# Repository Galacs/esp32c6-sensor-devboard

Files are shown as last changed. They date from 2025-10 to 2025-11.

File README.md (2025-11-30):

# ESP32-C6 Sensor-Devboard

ESP32-C6 sensor test board made to test step-down power supply design, wide input AC/DC level shifter, i2c temperature sensors, sdio sdcard and RF circuit (IEEE 802.15.4)

## IC List

- ESP32-C6 (Main MCU)
- W25Q128JVSIQ (16MB program storage spi flash)
- TCA9555 (I2C I/O expander)
- 2x TMP117 (I2C temperature sensor)
- BMP581 (I2C/SPI pressure sensor)
- 3x LM393 (comparator)
- 2x LMR36520 (wide Vin buck converter)
- LM317A (high Vin LDO)
- AP2112K (MCU LDO)
- 2x CJ431 (Voltage references)
- 2450AT18A100E (2.45GHz Ceramic chip antenna)

## Top preview



## Preview 3d render



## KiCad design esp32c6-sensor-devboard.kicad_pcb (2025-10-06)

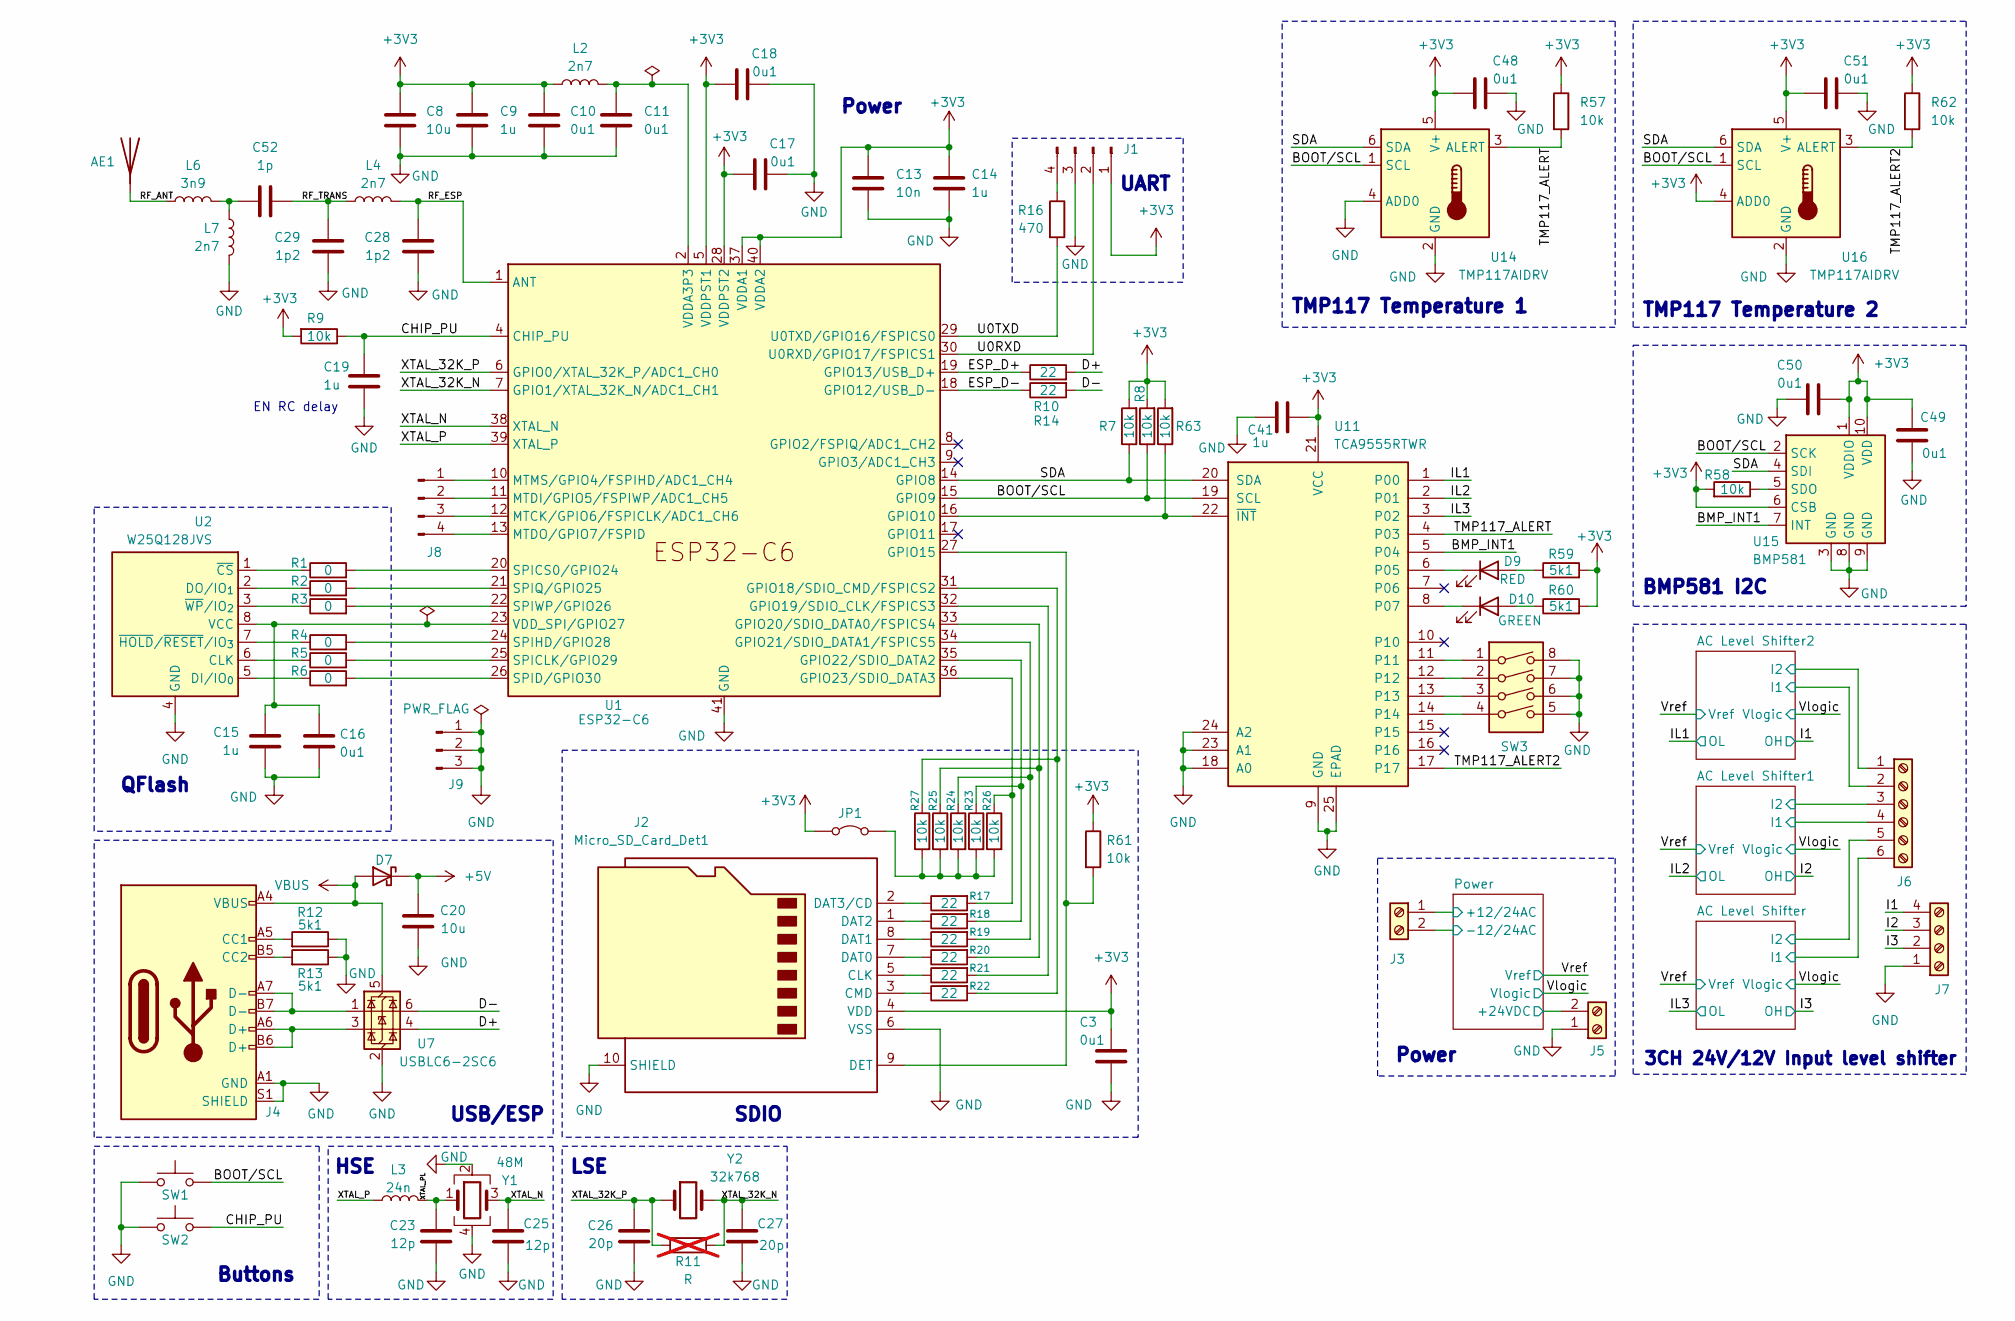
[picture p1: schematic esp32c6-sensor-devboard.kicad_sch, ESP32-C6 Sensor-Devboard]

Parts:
AE1: Antenna; Johanson_2450AT18x100; Manufacturer Part Number 2450AT18A100E; JLCPCB Part # C89334
C3: 0u1; C_0603_1608Metric; Manufacturer Part Number CC0603KRX7R9BB104; JLCPCB Part # C14663
C8, C20: 10u; C_0402_1005Metric; Manufacturer Part Number CL05A106MQ5NUNC; JLCPCB Part # C15525
C9, C14, C15, C19, C41: 1u; C_0402_1005Metric; Manufacturer Part Number CL05A105KA5NQNC; JLCPCB Part # C52923
C10, C11, C16, C17, C18, C48, C49, C50, C51: 0u1; C_0402_1005Metric; Manufacturer Part Number CL05B104KB54PNC; JLCPCB Part # C307331
C13: 10n; C_0402_1005Metric; Manufacturer Part Number CL05B103KB5NNNC; JLCPCB Part # C15195
C23, C25: 12p; C_0402_1005Metric; Manufacturer Part Number 0402CG120J500NT; JLCPCB Part # C1547
C26, C27: 20p; C_0402_1005Metric; Manufacturer Part Number 0402CG200J500NT; JLCPCB Part # C1554
C28, C29: 1p2; C_0402_1005Metric; Manufacturer Part Number GJM1555C1H1R2WB01D; JLCPCB Part # C76899
C52: 1p; C_0402_1005Metric; Manufacturer Part Number 0402CG1R0C500NT; JLCPCB Part # C1550
D7: D_Schottky; D_SMA; Manufacturer Part Number SS54; JLCPCB Part # C22452
D9: RED; LED_0603_1608Metric; Manufacturer Part Number KT-0603R; JLCPCB Part # C2286
D10: GREEN; LED_0805_2012Metric; Manufacturer Part Number KT-0805G; JLCPCB Part # C2297
J1, J8: Conn_01x04_Pin; PinHeader_1x04_P2.54mm_Vertical
J2: Micro_SD_Card_Det1; microSD_Hanbo_TF012; Manufacturer Part Number TF-012; JLCPCB Part # C410350
J3, J5: Screw_Terminal_01x02; TerminalBlock_Altech_AK300-2_P5.00mm
J4: USB_C_Receptacle_USB2.0_14P; USB_C_Receptacle_HRO_TYPE-C-31-M-12; Manufacturer Part Number TYPE-C16PIN; JLCPCB Part # C393939
J6: Screw_Terminal_01x06; TerminalBlock_Phoenix_MKDS-1,5-6_1x06_P5.00mm_Horizontal
J7: Screw_Terminal_01x04; TerminalBlock_Altech_AK300-4_P5.00mm
J9: Conn_01x03_Pin; PinHeader_1x03_P2.54mm_Vertical
JP1: Jumper_2_Bridged; PinHeader_1x02_P2.54mm_Vertical
L2, L4: 2n7; L_0402_1005Metric; Manufacturer Part Number LQW15AN2N7G80D; JLCPCB Part # C412269
L3: 24n; L_0402_1005Metric; Manufacturer Part Number LQW15AN24NG00D; JLCPCB Part # C167472
L6: 3n9; L_0402_1005Metric; Manufacturer Part Number LQG15HS3N9S02D; JLCPCB Part # C77109
L7: 2n7; L_0402_1005Metric; Manufacturer Part Number LQG15HS2N7S02D; JLCPCB Part # C77108
R1, R2, R3, R4, R5, R6: 0; R_0402_1005Metric; Manufacturer Part Number 0402WGF0000TCE; JLCPCB Part # C17168
R7, R8, R9, R57, R58, R61, R62, R63: 10k; R_0603_1608Metric; Manufacturer Part Number 0603WAF1002T5E; JLCPCB Part # C25804
R10, R14, R17, R18, R19, R20, R21, R22: 22; R_0402_1005Metric; Manufacturer Part Number 0402WGF220JTCE; JLCPCB Part # C25092
R11: R; R_0603_1608Metric; not fitted
R12, R13, R59, R60: 5k1; R_0603_1608Metric; Manufacturer Part Number 0603WAF5101T5E; JLCPCB Part # C23186
R16: 470; R_0402_1005Metric; Manufacturer Part Number 0402WGF4700TCE; JLCPCB Part # C25117
R23, R24, R25, R26, R27: 10k; R_0402_1005Metric; Manufacturer Part Number 0402WGF1002TCE; JLCPCB Part # C25744
SW1, SW2: SW_Push; SW_SPST_TS-1088-xR020; Manufacturer Part Number TS-1088-AR02016; JLCPCB Part # C720477
SW3: SW_DIP_x04; SW_DIP_SPSTx04_Slide_9.78x12.34mm_W7.62mm_P2.54mm
U1: ESP32-C6; QFN-40-1EP_5x5mm_P0.4mm_EP3.6x3.6mm_ThermalVias; Manufacturer Part Number ESP32-C6; JLCPCB Part # C5364646
U2: W25Q128JVS; SOIC-8_5.3x5.3mm_P1.27mm; Manufacturer Part Number W25Q128JVSIQ; JLCPCB Part # C97521
U7: USBLC6-2SC6; SOT-23-6; Manufacturer Part Number USBLC6-2SC6; JLCPCB Part # C7519
U11: TCA9555RTWR; Texas_RTW_WQFN-24-1EP_4x4mm_P0.5mm_EP2.7x2.7mm_ThermalVias; Manufacturer Part Number TCA9555RTWR; JLCPCB Part # C140277
U14, U16: TMP117AIDRV; WSON-6-1EP_2x2mm_P0.65mm_EP1x1.6mm; Manufacturer Part Number TMP117AIDRVR; JLCPCB Part # C699536
U15: BMP581; Bosch_LGA-10_2x2mm_P0.8mm_AntiClockwisePinNumbering; Manufacturer Part Number BMP581; JLCPCB Part # C5362283
Y1: 48M; Crystal_SMD_2016-4Pin_2.0x1.6mm; Manufacturer Part Number R940000096; JLCPCB Part # C7206306
Y2: 32k768; Crystal_SMD_3215-2Pin_3.2x1.5mm; Manufacturer Part Number Q13FC13500004; JLCPCB Part # C32346

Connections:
+3V3: C3.1, C8.1, C9.1, C10.1, C13.1, C14.1, C17.1, C18.1, C41.2, C48.1, C49.2, C50.1, C51.1, J1.1, J2.4 (VDD), JP1.1 (A), L2.1, R7.2, R8.2, R9.2, R57.1, R58.2, R59.2, R60.2, R61.1, R62.1, R63.2, U1.5 (VDDPST1), U1.28 (VDDPST2), U1.37 (VDDA1), U1.40 (VDDA2), U11.21 (VCC), U14.5 (V+), U15.1 (VDDIO), U15.6 (CSB), U15.10 (VDD), U16.4 (ADD0), U16.5 (V+); also elsewhere on the board
+5V: C20.1, D7.1 (K); also elsewhere on the board
/AC Level Shifter1/I1: J6.4; also elsewhere on the board
/AC Level Shifter1/I2: J6.3; also elsewhere on the board
/AC Level Shifter2/I1: J6.2; also elsewhere on the board
/AC Level Shifter2/I2: J6.1; also elsewhere on the board
/AC Level Shifter/I1: J6.6; also elsewhere on the board
/AC Level Shifter/I2: J6.5; also elsewhere on the board
/BMP_INT1: U11.5 (P04), U15.7 (INT)
/BOOT/SCL: R8.1, SW1.2, U1.15 (GPIO9), U11.19 (SCL), U14.1 (SCL), U15.2 (SCK), U16.1 (SCL)
/CHIP_PU: C19.1, R9.1, SW2.2, U1.4 (CHIP_PU)
/D+: R10.2, U7.4 (I/O2)
/D-: R14.2, U7.6 (I/O1)
/ESP_D+: R10.1, U1.19 (GPIO13/USB_D+)
/ESP_D-: R14.1, U1.18 (GPIO12/USB_D-)
/I1: J7.4; also elsewhere on the board
/I2: J7.3; also elsewhere on the board
/I3: J7.2; also elsewhere on the board
/IL1: U11.1 (P00); also elsewhere on the board
/IL2: U11.2 (P01); also elsewhere on the board
/IL3: U11.3 (P02); also elsewhere on the board
/Power/+12/24AC: J3.1; also elsewhere on the board
/Power/+24VDC: J5.2; also elsewhere on the board
/Power/-12/24AC: J3.2; also elsewhere on the board
/RF_ANT: AE1.1 (A), L6.1
/RF_ESP: C28.1, L4.2, U1.1 (ANT)
/RF_TRANS: C29.1, C52.1, L4.1
/SDA: R7.1, U1.14 (GPIO8), U11.20 (SDA), U14.6 (SDA), U15.4 (SDI), U16.6 (SDA)
/TMP117_ALERT: R57.2, U11.4 (P03), U14.3 (ALERT)
/TMP117_ALERT2: R62.2, U11.17, U16.3 (ALERT)
/U0RXD: J1.2, U1.30 (U0RXD/GPIO17/FSPICS1)
/U0TXD: R16.2, U1.29 (U0TXD/GPIO16/FSPICS0)
/XTAL_32K_N: C27.1, R11.2, U1.7 (GPIO1/XTAL_32K_N/ADC1_CH1), Y2.2
/XTAL_32K_P: C26.2, R11.1, U1.6 (GPIO0/XTAL_32K_P/ADC1_CH0), Y2.1
/XTAL_N: C25.1, U1.38 (XTAL_N), Y1.3
/XTAL_P: L3.1, U1.39 (XTAL_P)
/XTAL_PL: C23.2, L3.2, Y1.1
GND: C3.2, C8.2, C9.2, C10.2, C11.2, C13.2, C14.2, C15.2, C16.2, C17.2, C18.2, C19.2, C20.2, C23.1, C25.2, C26.1, C27.2, C28.2, C29.2, C41.1, C48.2, C49.1, C50.2, C51.2, J1.3, J2.6 (VSS), J2.10 (SHIELD), J4.A1 (GND), J4.A12 (GND), J4.B1 (GND), J4.B12 (GND), J4.S1 (SHIELD), J5.1, J7.1, J9.1, J9.2, J9.3, L7.1, R12.1, R13.1, SW1.1, SW2.1, SW3.5, SW3.6, SW3.7, SW3.8, U1.41 (GND), U2.4 (GND), U7.2 (GND), U11.9 (GND), U11.18 (A0), U11.23 (A1), U11.24 (A2), U11.25 (EPAD), U14.2 (GND), U14.4 (ADD0), U15.3 (GND), U15.8 (GND), U15.9 (GND), U16.2 (GND), U16.7, Y1.2, Y1.4; also elsewhere on the board
unnamed: C11.1, L2.2, U1.2 (VDDA3P3), U1.3 (VDDA3P3)
unnamed: C52.2, L6.2, L7.2
unnamed: D9.2 (A), R59.1
unnamed: D9.1 (K), U11.6 (P05)
unnamed: D10.2 (A), R60.1
unnamed: D10.1 (K), U11.8 (P07)
unnamed: J1.4, R16.1
unnamed: J2.5 (CLK), R21.1
unnamed: J2.3 (CMD), R22.1
unnamed: J2.7 (DAT0), R20.1
unnamed: J2.8 (DAT1), R19.1
unnamed: J2.1 (DAT2), R18.1
unnamed: J2.2 (DAT3/CD), R17.1
unnamed: J2.9 (DET), R61.2, U1.27 (GPIO15)
unnamed: J4.A5 (CC1), R12.2
unnamed: J4.B5 (CC2), R13.2
unnamed: J4.A6 (D+), J4.B6 (D+), U7.3 (I/O2)
unnamed: J4.A7 (D-), J4.B7 (D-), U7.1 (I/O1)
unnamed: J8.1, U1.10 (MTMS/GPIO4/FSPIHD/ADC1_CH4)
unnamed: J8.2, U1.11 (MTDI/GPIO5/FSPIWP/ADC1_CH5)
unnamed: J8.3, U1.12 (MTCK/GPIO6/FSPICLK/ADC1_CH6)
unnamed: J8.4, U1.13 (MTDO/GPIO7/FSPID)
unnamed: JP1.2 (B), R23.2, R24.2, R25.2, R26.2, R27.2
unnamed: R63.1, U1.16 (GPIO10), U11.22 (~INT)
unnamed: R22.2, R27.1, U1.31 (GPIO18/SDIO_CMD/FSPICS2)
unnamed: R21.2, U1.32 (GPIO19/SDIO_CLK/FSPICS3)
unnamed: R20.2, R25.1, U1.33 (GPIO20/SDIO_DATA0/FSPICS4)
unnamed: R19.2, R24.1, U1.34 (GPIO21/SDIO_DATA1/FSPICS5)
unnamed: R18.2, R23.1, U1.35 (GPIO22/SDIO_DATA2)
unnamed: R17.2, R26.1, U1.36 (GPIO23/SDIO_DATA3)
unnamed: R5.2, U1.25 (SPICLK/GPIO29)
unnamed: R1.2, U1.20 (SPICS0/GPIO24)
unnamed: R6.2, U1.26 (SPID/GPIO30)
unnamed: R4.2, U1.24 (SPIHD/GPIO28)
unnamed: R2.2, U1.21 (SPIQ/GPIO25)
unnamed: R3.2, U1.22 (SPIWP/GPIO26)
unnamed: C15.1, C16.1, U1.23 (VDD_SPI/GPIO27), U2.8 (VCC)
unnamed: R5.1, U2.6 (CLK)
unnamed: R6.1, U2.5 (DI/IO_{0})
unnamed: R2.1, U2.2 (DO/IO_{1})
unnamed: R1.1, U2.1 (~CS)
unnamed: R4.1, U2.7 (~HOLD/~RESET/IO_{3})
unnamed: R3.1, U2.3 (~WP/IO_{2})
unnamed: SW3.1, U11.11
unnamed: SW3.2, U11.12
unnamed: SW3.3, U11.13
unnamed: SW3.4, U11.14
unnamed: R58.1, U15.5 (SDO)
TMP117_1_PAD: U14.7
VBUS: D7.2 (A), J4.A4 (VBUS), J4.A9 (VBUS), J4.B4 (VBUS), J4.B9 (VBUS), U7.5 (VBUS)

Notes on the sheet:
BMP581 I2C
TMP117 Temperature 2
EN RC delay
HSE
3CH 24V/12V Input level shifter
SDIO
LSE
TMP117 Temperature 1
QFlash
Power
USB/ESP
Buttons
UART

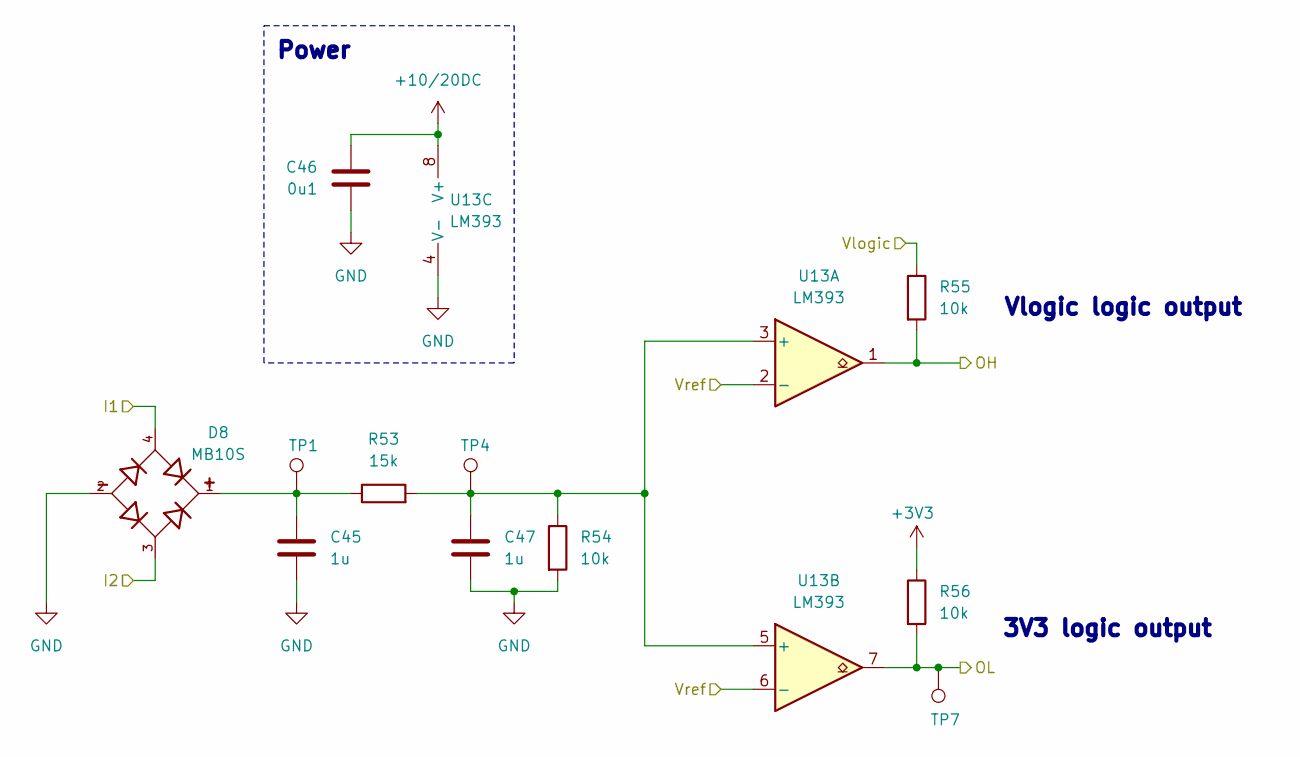
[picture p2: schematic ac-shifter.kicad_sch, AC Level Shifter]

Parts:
C45: 1u; C_0603_1608Metric; Manufacturer Part Number CL10A105KB8NNNC; JLCPCB Part # C15849
C46: 0u1; C_0402_1005Metric; Manufacturer Part Number CL05B104KB54PNC; JLCPCB Part # C307331
C47: 1u; C_0402_1005Metric; Manufacturer Part Number CL05A105KA5NQNC; JLCPCB Part # C52923
D8: MB10S; OnSemi_751EP_SOIC-4_3.9x4.725mm_P2.54mm; Manufacturer Part Number C2488; JLCPCB Part # C2488
R53: 15k; R_0603_1608Metric; Manufacturer Part Number 0603WAF1502T5E; JLCPCB Part # C22809
R54, R55, R56: 10k; R_0603_1608Metric; Manufacturer Part Number 0603WAF1002T5E; JLCPCB Part # C25804
TP1, TP4, TP7: TestPoint; TestPoint_Pad_D2.0mm
U13: LM393; SOIC-8_3.9x4.9mm_P1.27mm; Manufacturer Part Number LM393DR2G; JLCPCB Part # C7955

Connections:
+3V3: R56.1; also elsewhere on the board
+10/20DC: C46.1, U13.8 (V+); also elsewhere on the board
/AC Level Shifter/I1: D8.4; also elsewhere on the board
/AC Level Shifter/I2: D8.3; also elsewhere on the board
/I3: R55.2, U13.1; also elsewhere on the board
/IL3: R56.2, TP7.1, U13.7; also elsewhere on the board
/Vlogic: R55.1; also elsewhere on the board
/Vref: U13.2 (-), U13.6 (-); also elsewhere on the board
GND: C45.2, C46.2, C47.2, D8.2, R54.2, U13.4 (V-); also elsewhere on the board
unnamed: C45.1, D8.1, R53.1, TP1.1
unnamed: C47.1, R53.2, R54.1, TP4.1, U13.3 (+), U13.5 (+)

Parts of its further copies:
C32, C42: 1u; C_0603_1608Metric; Manufacturer Part Number CL10A105KB8NNNC; JLCPCB Part # C15849
C39, C43: 0u1; C_0402_1005Metric; Manufacturer Part Number CL05B104KB54PNC; JLCPCB Part # C307331
C40, C44: 1u; C_0402_1005Metric; Manufacturer Part Number CL05A105KA5NQNC; JLCPCB Part # C52923
D5, D6: MB10S; OnSemi_751EP_SOIC-4_3.9x4.725mm_P2.54mm; Manufacturer Part Number C2488; JLCPCB Part # C2488
R37, R49: 15k; R_0603_1608Metric; Manufacturer Part Number 0603WAF1502T5E; JLCPCB Part # C22809
R39, R47, R48, R50, R51, R52: 10k; R_0603_1608Metric; Manufacturer Part Number 0603WAF1002T5E; JLCPCB Part # C25804
TP2, TP3, TP5, TP6, TP8, TP9: TestPoint; TestPoint_Pad_D2.0mm
U10, U12: LM393; SOIC-8_3.9x4.9mm_P1.27mm; Manufacturer Part Number LM393DR2G; JLCPCB Part # C7955

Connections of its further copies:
+3V3: R48.1, R52.1; also elsewhere on the board
+10/20DC: C39.1, C43.1, U10.8 (V+), U12.8 (V+); also elsewhere on the board
/AC Level Shifter1/I1: D6.4; also elsewhere on the board
/AC Level Shifter1/I2: D6.3; also elsewhere on the board
/AC Level Shifter2/I1: D5.4; also elsewhere on the board
/AC Level Shifter2/I2: D5.3; also elsewhere on the board
/I1: R47.2, U10.1; also elsewhere on the board
/I2: R51.2, U12.1; also elsewhere on the board
/IL1: R48.2, TP9.1, U10.7; also elsewhere on the board
/IL2: R52.2, TP8.1, U12.7; also elsewhere on the board
/Vlogic: R47.1, R51.1; also elsewhere on the board
/Vref: U10.2 (-), U10.6 (-), U12.2 (-), U12.6 (-); also elsewhere on the board
GND: C32.2, C39.2, C40.2, C42.2, C43.2, C44.2, D5.2, D6.2, R39.2, R50.2, U10.4 (V-), U12.4 (V-); also elsewhere on the board
unnamed: C32.1, D5.1, R37.1, TP3.1
unnamed: C42.1, D6.1, R49.1, TP2.1
unnamed: C40.1, R37.2, R39.1, TP6.1, U10.3 (+), U10.5 (+)
unnamed: C44.1, R49.2, R50.1, TP5.1, U12.3 (+), U12.5 (+)

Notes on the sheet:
Power
3V3 logic output
Vlogic logic output

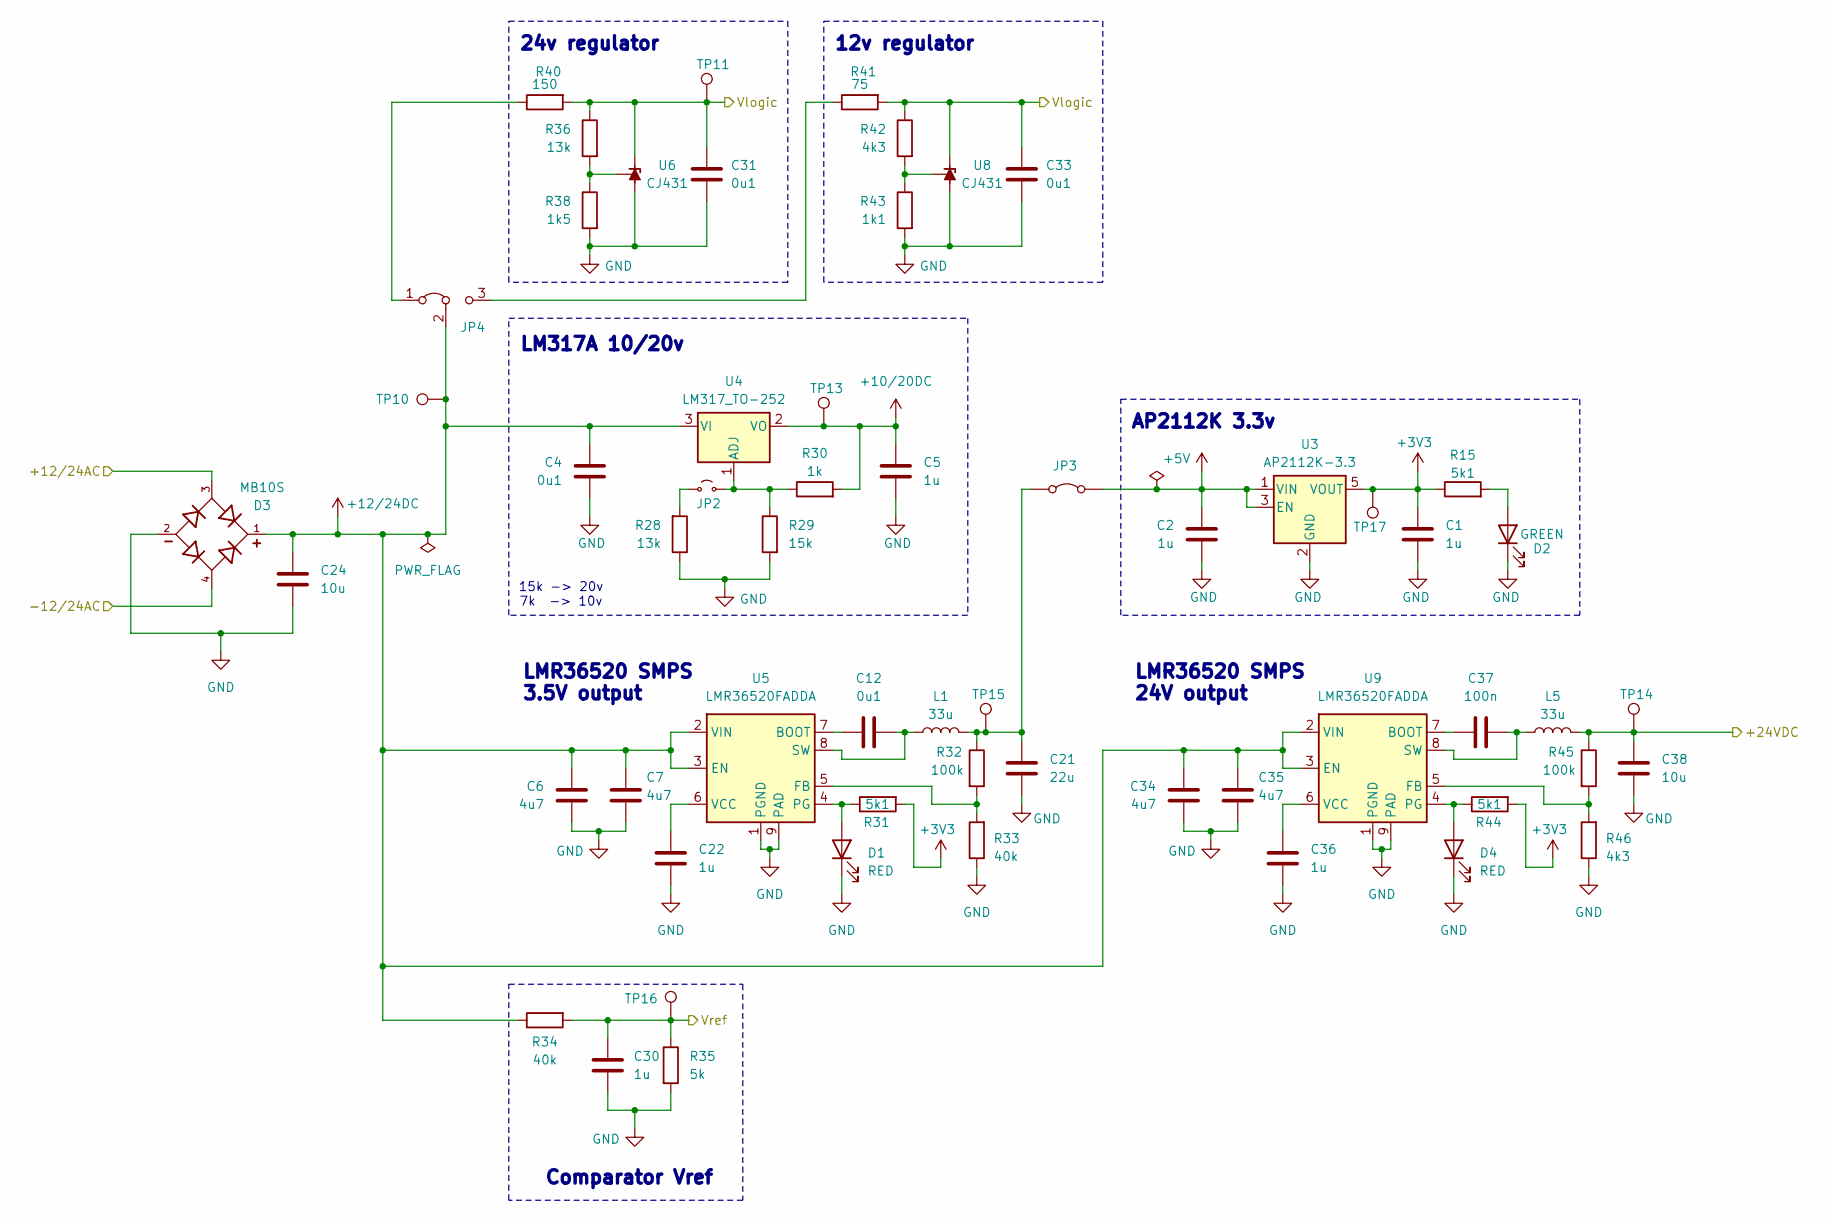
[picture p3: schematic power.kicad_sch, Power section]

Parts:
C1, C2, C5: 1u; C_0603_1608Metric; Manufacturer Part Number CL10A105KB8NNNC; JLCPCB Part # C15849
C4: 0u1; C_0603_1608Metric; Manufacturer Part Number CC0603KRX7R9BB104; JLCPCB Part # C14663
C6, C7, C34, C35: 4u7; C_1206_3216Metric; Manufacturer Part Number 1206B475K500NT; JLCPCB Part # C29823
C12, C31, C33: 0u1; C_0402_1005Metric; Manufacturer Part Number CL05B104KB54PNC; JLCPCB Part # C307331
C21: 22u; C_0603_1608Metric; Manufacturer Part Number CL10A226MQ8NRNC; JLCPCB Part # C59461
C22, C30, C36: 1u; C_0402_1005Metric; Manufacturer Part Number CL05A105KA5NQNC; JLCPCB Part # C52923
C24: 10u; C_0805_2012Metric; Manufacturer Part Number GRM21BR61H106KE43L; JLCPCB Part # C440198
C37: 100n; C_0402_1005Metric; Manufacturer Part Number CL05B104KB54PNC; JLCPCB Part # C307331
C38: 10u; C_0603_1608Metric; Manufacturer Part Number CL10A106MA8NRNC; JLCPCB Part # C96446
D1, D4: RED; LED_0603_1608Metric; Manufacturer Part Number KT-0603R; JLCPCB Part # C2286
D2: GREEN; LED_0805_2012Metric; Manufacturer Part Number KT-0805G; JLCPCB Part # C2297
D3: MB10S; OnSemi_751EP_SOIC-4_3.9x4.725mm_P2.54mm; Manufacturer Part Number C2488; JLCPCB Part # C2488
JP2: Jumper_2_Small_Open; PinHeader_1x02_P2.54mm_Vertical
JP3: Jumper_2_Bridged; PinHeader_1x02_P2.54mm_Vertical
JP4: Jumper_3_Bridged12; PinHeader_1x03_P2.54mm_Vertical
L1, L5: 33u; L_Chilisin_BMRx00060630; Manufacturer Part Number FXL0630-330-M; JLCPCB Part # C177245
R15, R31, R44: 5k1; R_0603_1608Metric; Manufacturer Part Number 0603WAF5101T5E; JLCPCB Part # C23186
R28, R36: 13k; R_0603_1608Metric; Manufacturer Part Number 0603WAF1302T5E; JLCPCB Part # C22797
R29: 15k; R_0603_1608Metric; Manufacturer Part Number 0603WAF1502T5E; JLCPCB Part # C22809
R30: 1k; R_0603_1608Metric; Manufacturer Part Number 0603WAF1001T5E; JLCPCB Part # C21190
R32, R45: 100k; R_0603_1608Metric; Manufacturer Part Number 0603WAF1003T5E; JLCPCB Part # C25803
R33, R34: 40k; R_0603_1608Metric; Manufacturer Part Number 0603WAF4022T5E; JLCPCB Part # C12447
R35: 5k; R_0603_1608Metric; Manufacturer Part Number 0603WAF4991T5E; JLCPCB Part # C23046
R38: 1k5; R_0603_1608Metric; Manufacturer Part Number 0603WAF1501T5E; JLCPCB Part # C22843
R40: 150; R_0805_2012Metric; Manufacturer Part Number 0805W8F1500T5E; JLCPCB Part # C17471
R41: 75; R_0805_2012Metric; Manufacturer Part Number 0805W8F750JT5E; JLCPCB Part # C20638
R42, R46: 4k3; R_0603_1608Metric; Manufacturer Part Number 0603WAF4301T5E; JLCPCB Part # C23159
R43: 1k1; R_0603_1608Metric; Manufacturer Part Number 0603WAF1101T5E; JLCPCB Part # C22764
TP10, TP11, TP13, TP14, TP15, TP16, TP17: TestPoint; TestPoint_Pad_D2.0mm
U3: AP2112K-3.3; SOT-23-5; Manufacturer Part Number AP2112K-3.3TRG1; JLCPCB Part # C51118
U4: LM317_TO-252; TO-252-2; Manufacturer Part Number LM317AG-TN3-R; JLCPCB Part # C75510
U5, U9: LMR36520FADDA; Texas_HTSOP-8-1EP_3.9x4.9mm_P1.27mm_EP2.95x4.9mm_Mask2.4x3.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; Manufacturer Part Number LMR36520FADDAR; JLCPCB Part # C1858395
U6, U8: CJ431; SOT-23; Manufacturer Part Number CJ431; JLCPCB Part # C3113

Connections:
+3V3: C1.1, R15.1, R31.2, R44.2, TP17.1, U3.5 (VOUT); also elsewhere on the board
+5V: C2.1, JP3.2 (B), U3.1 (VIN), U3.3 (EN); also elsewhere on the board
+10/20DC: C5.1, R30.2, TP13.1, U4.2 (VO); also elsewhere on the board
+12/24DC: C4.1, C6.1, C7.1, C24.1, C34.1, C35.1, D3.1, JP4.2 (C), R34.1, TP10.1, U4.3 (VI), U5.2 (VIN), U5.3 (EN), U9.2 (VIN), U9.3 (EN)
/Power/+12/24AC: D3.3; also elsewhere on the board
/Power/+24VDC: C38.2, L5.2, R45.1, TP14.1; also elsewhere on the board
/Power/-12/24AC: D3.4; also elsewhere on the board
/Vlogic: C31.1, C33.1, R36.1, R40.2, R41.2, R42.1, TP11.1, U6.2 (K), U8.2 (K); also elsewhere on the board
/Vref: C30.1, R34.2, R35.1, TP16.1; also elsewhere on the board
GND: C1.2, C2.2, C4.2, C5.2, C6.2, C7.2, C21.1, C22.2, C24.2, C30.2, C31.2, C33.2, C34.2, C35.2, C36.2, C38.1, D1.1 (K), D2.1 (K), D3.2, D4.1 (K), R28.1, R29.2, R33.1, R35.2, R38.2, R43.2, R46.1, U3.2 (GND), U5.1 (PGND), U5.9 (PAD), U6.3 (A), U8.3 (A), U9.1 (PGND), U9.9 (PAD); also elsewhere on the board
unnamed: D1.2 (A), R31.1, U5.4 (PG)
unnamed: D2.2 (A), R15.2
unnamed: D4.2 (A), R44.1, U9.4 (PG)
unnamed: JP2.1 (A), R28.2
unnamed: JP2.2 (B), R29.1, R30.1, U4.1 (ADJ)
unnamed: C21.2, JP3.1 (A), L1.2, R32.1, TP15.1
unnamed: JP4.1 (A), R40.1
unnamed: JP4.3 (B), R41.1
unnamed: C12.2, U5.7 (BOOT)
unnamed: R32.2, R33.2, U5.5 (FB)
unnamed: C12.1, L1.1, U5.8 (SW)
unnamed: C22.1, U5.6 (VCC)
unnamed: R36.2, R38.1, U6.1 (REF)
unnamed: R42.2, R43.1, U8.1 (REF)
unnamed: C37.2, U9.7 (BOOT)
unnamed: R45.2, R46.2, U9.5 (FB)
unnamed: C37.1, L5.1, U9.8 (SW)
unnamed: C36.1, U9.6 (VCC)

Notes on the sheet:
Comparator Vref
LMR36520 SMPS 3.5V output
AP2112K 3.3v
12v regulator
15k -> 20v 7k -> 10v
24v regulator
LMR36520 SMPS 24V output
LM317A 10/20v

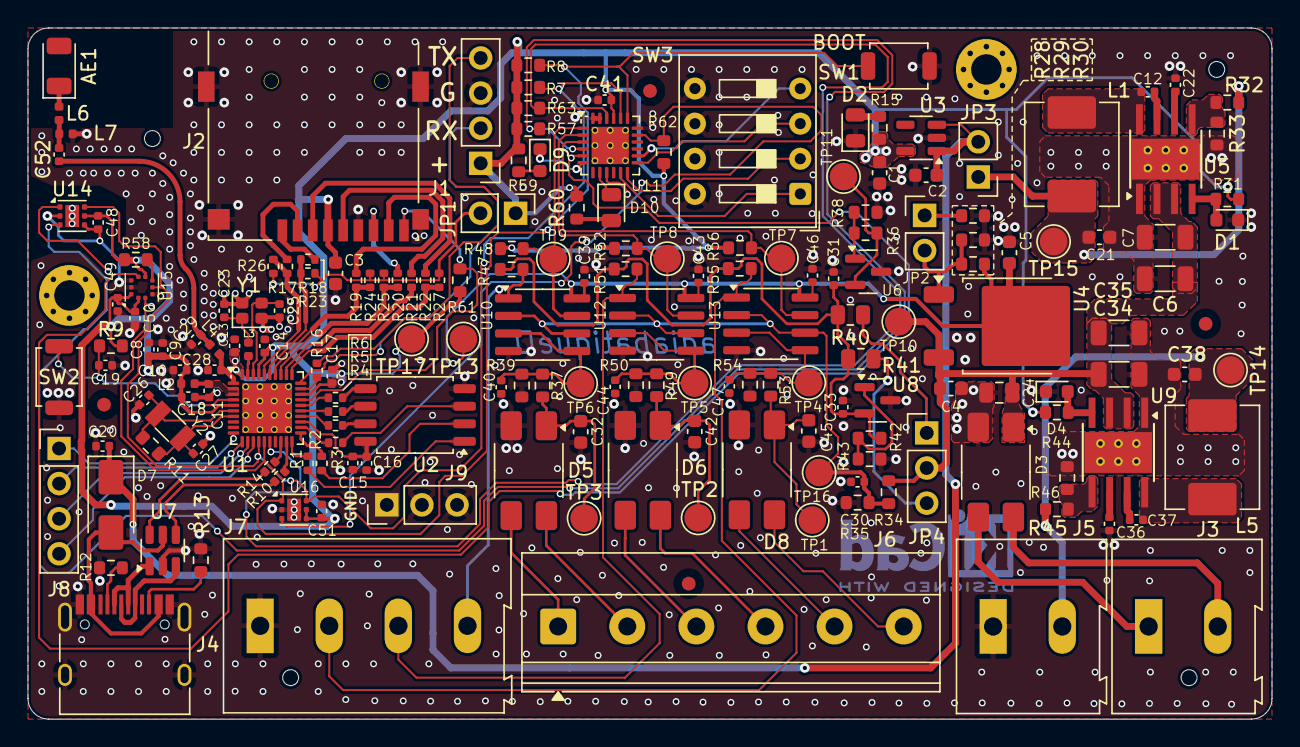
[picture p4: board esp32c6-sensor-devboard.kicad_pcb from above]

Board: 4 copper layers, 90.0 x 50.0 mm, 183 parts (0 on the bottom side), 115 nets.

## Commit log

2025-09-07 schem: add esp32-c6 symbol
    [esp32c6-sensor-devboard.kicad_sch]
2025-09-07 schem: add W25Q128JVS 16MB flash
    [esp32c6-sensor-devboard.kicad_sch]
2025-09-07 schem: add low and high speed crystals
    [esp32c6-sensor-devboard.kicad_sch]
2025-09-07 schem: add strapping pins and btns
    [esp32c6-sensor-devboard.kicad_sch]
2025-09-07 schem: add usb c connector
    [esp32c6-sensor-devboard.kicad_sch]
2025-09-07 schem: add AP2112K 3.3v ldo regulator
    [esp32c6-sensor-devboard.kicad_sch]
2025-09-07 schem: add rf antenna
    [esp32c6-sensor-devboard.kicad_sch]
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2025-09-08 schem: add uart header
    [esp32c6-sensor-devboard.kicad_sch]
2025-09-08 schem: add uart series restistor
    [esp32c6-sensor-devboard.kicad_sch]
2025-09-08 schem: add sdcard slot
    [esp32c6-sensor-devboard.kicad_sch]
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2025-09-15 schem: add LM317A 10/20v ldo
    [esp32c6-sensor-devboard.kicad_sch]
2025-09-15 schem: add sdio nets area rule
    [esp32c6-sensor-devboard.kicad_sch]
2025-09-17 schem: add LMR36520 components
    [esp32c6-sensor-devboard.kicad_sch]
2025-09-17 schem: add LMR36520 components values
    [esp32c6-sensor-devboard.kicad_sch]
2025-09-19 schem: add SMPS power input
    [esp32c6-sensor-devboard.kicad_sch]
2025-09-19 schem: move power to subsheet and add rectifier
    [esp32c6-sensor-devboard.kicad_sch, power.kicad_sch]
2025-09-21 schem: add ac 24/12v level shifter
    [ac-shifter.kicad_sch, esp32c6-sensor-devboard.kicad_sch]
2025-09-22 schem: add CJ431 24v & 12v voltage references
    [esp32c6-sensor-devboard.kicad_sch, power.kicad_sch]
2025-09-23 schem: add LMR36520 24v smps
    [esp32c6-sensor-devboard.kicad_sch, power.kicad_sch]
2025-09-23 schem: annotate back ac level shifter page
    [ac-shifter.kicad_sch]
2025-09-24 schem: add TCA9555 I/O expander
    [esp32c6-sensor-devboard.kicad_sch]
2025-09-24 schem: add 3CH 24V/12V Input level shifter
    [3ch-level-shifter.kicad_sch, ac-shifter.kicad_sch, esp32c6-sensor-devboard.kicad_sch]
2025-09-24 schem: add comparator test points
    [ac-shifter.kicad_sch]
2025-09-24 schem: add power test points
    [ac-shifter.kicad_sch, power.kicad_sch]
2025-09-26 schem: add TMP117 temperature sensor
    [esp32c6-sensor-devboard.kicad_sch]
2025-09-26 schem: add BMP581 I2C pressure sensor
    [esp32c6-sensor-devboard.kicad_sch]
2025-09-26 schem: BMP581 I2C CSB selection
    [esp32c6-sensor-devboard.kicad_sch]
2025-09-26 schem: add 2 LED indicators
    [esp32c6-sensor-devboard.kicad_sch]
2025-09-26 schem: add dip switches
    [esp32c6-sensor-devboard.kicad_sch]
2025-09-26 schem: add spare pins headers
    [esp32c6-sensor-devboard.kicad_sch]
2025-09-26 schem: annotation clean up
    [esp32c6-sensor-devboard.kicad_sch]
2025-09-26 schem: add SD card DET pull-up
    [esp32c6-sensor-devboard.kicad_sch]
2025-09-26 schem: add no connects
    [esp32c6-sensor-devboard.kicad_sch]
2025-09-26 schem: add sheet titles
    [ac-shifter.kicad_sch, esp32c6-sensor-devboard.kicad_sch, power.kicad_sch]
2025-09-26 schem: fix erc
    [esp32c6-sensor-devboard.kicad_sch, power.kicad_sch]
2025-09-27 schem: fix alignement
    [esp32c6-sensor-devboard.kicad_sch]
2025-09-27 schem: add second TMP117 temp sensor
    [esp32c6-sensor-devboard.kicad_sch]
2025-09-27 schem: connect TCA9555 IO expander INT pin
    [esp32c6-sensor-devboard.kicad_sch]
2025-09-27 schem: add +3V3 test point
    [power.kicad_sch]
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2025-09-27 schem: add part numbers to BOM
    [ac-shifter.kicad_sch, esp32c6-sensor-devboard.kicad_sch, power.kicad_sch]
2025-09-28 schem: add PCA9555 interupt pin pull-up
    [esp32c6-sensor-devboard.kicad_sch]
2025-09-28 schem: add remaining part numbers to BOM
    [ac-shifter.kicad_sch, esp32c6-sensor-devboard.kicad_sch, power.kicad_sch]
2025-09-28 schem: fix UBS C receptacle hidden power pins
    [esp32c6-sensor-devboard.kicad_sch]
2025-09-28 pcb: create pcb file
    [esp32c6-sensor-devboard.kicad_pcb]
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2025-09-28 pcb: import components from schematic
    [esp32c6-sensor-devboard.kicad_pcb]
2025-09-28 schem/pcb: update MB10S footprint
    [ac-shifter.kicad_sch, esp32c6-sensor-devboard.kicad_pcb, power.kicad_sch]
2025-09-28 pcb: add missing 3d models
    [esp32c6-sensor-devboard.kicad_pcb, esp32c6-sensor-devboard.kicad_sch]
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2025-09-28 pcb: initial rough pcb placement
    [esp32c6-sensor-devboard.kicad_pcb, esp32c6-sensor-devboard.kicad_sch, power.kicad_sch]
2025-09-28 schem/pcb: add antenna matching network
    [esp32c6-sensor-devboard.kicad_pcb, esp32c6-sensor-devboard.kicad_sch]
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2025-09-29 pcb: shunt regulators layout
    [esp32c6-sensor-devboard.kicad_pcb, power.kicad_sch]
2025-09-29 pcb: usb connector layout
    [esp32c6-sensor-devboard.kicad_pcb]
2025-09-29 pcb: ac level shifter layout
    [ac-shifter.kicad_sch, esp32c6-sensor-devboard.kicad_pcb]
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2025-09-29 pcb: spi flash layout
    [esp32c6-sensor-devboard.kicad_pcb]
2025-09-29 pcb: fix 3v3 ldo layout
    [esp32c6-sensor-devboard.kicad_pcb]
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2025-09-29 pcb: add board outline
    [esp32c6-sensor-devboard.kicad_pcb]
2025-09-29 pcb: add inner gnd planes
    [esp32c6-sensor-devboard.kicad_pcb]
2025-09-29 pcb: add tooling holes
    [esp32c6-sensor-devboard.kicad_pcb]
2025-09-29 pcb: add M2 mounting holes
    [esp32c6-sensor-devboard.kicad_pcb]
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2025-09-29 pcb: add gnd vias
    [esp32c6-sensor-devboard.kicad_pcb]
2025-09-29 pcb: add smps routing
    [esp32c6-sensor-devboard.kicad_pcb]
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2025-10-01 pcb: fix bottom layer traces
    [esp32c6-sensor-devboard.kicad_pcb]
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2025-10-02 pcb: make TMP117 keepout area go trough all layers
    [esp32c6-sensor-devboard.kicad_pcb]
2025-10-02 pcb: fix TMP117 bottom heatsink copper
    [esp32c6-sensor-devboard.kicad_pcb]
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2025-10-06 pcb: run and fix DRC
    [esp32c6-sensor-devboard.kicad_pcb]
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
